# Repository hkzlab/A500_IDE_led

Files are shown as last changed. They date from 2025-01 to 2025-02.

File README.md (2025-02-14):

# A500 IDE activity led injector

## DISCLAIMER

Any use of this project is **under your own responsibility**.
You will be responsible of checking the correct construction and functionality of your board.
By using this project You will agree that I cannot be held responsible if it will destroy any of your devices, damage your computer, burn down your house or whatever.

## Introduction

This board reproduces the same circuit that the A500 uses to flash the "DRIVE" LED when the `/MTR0` signal is toggled, and puts itself in parallel to that 
by being installed between the keyboard and the connector on the motherboard.

It is useful to have the LED blink for other activity beside the floppy's, ideally, IDE hard drive activity.

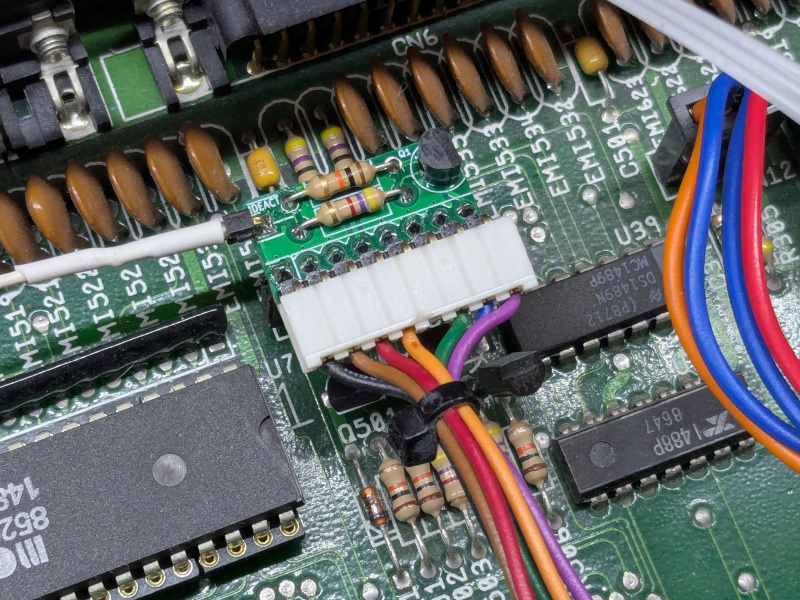
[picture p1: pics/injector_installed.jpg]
Board installed in an A500 rev.3


The IDE activity signal must then be taken from the IDE connector, on a 44 pin connector, it is on pin 39.

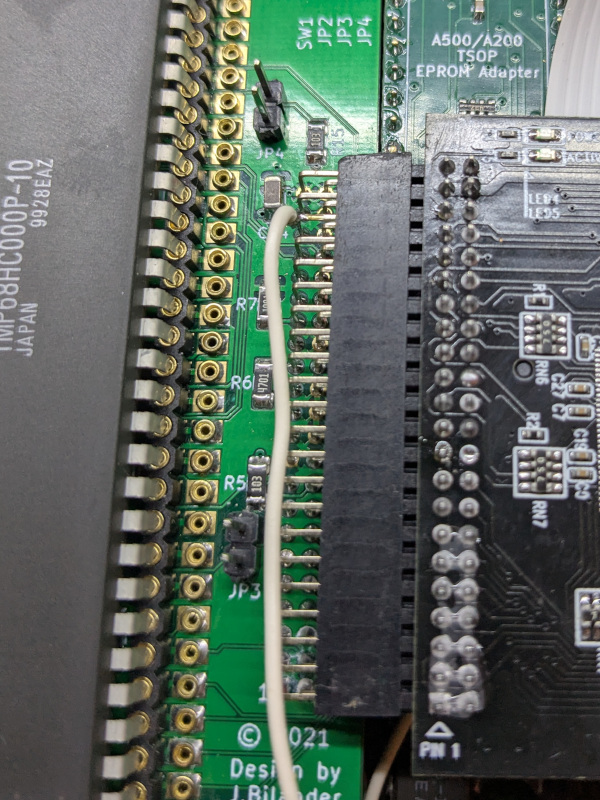
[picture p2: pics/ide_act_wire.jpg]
Wire soldered on connector pin 39


### Ordering the boards

You can order the board for this project at [PCBWay](https://www.pcbway.com/project/shareproject/A500_IDE_LED_mod_board_fed31fc6.html) and support me or download 
the gerbers and have them printed wherever you like!!!

## Hardware

The board was designed with [KiCad](https://kicad.org/) EDA.

### Bill of Materials

| Component | Qty | Type / Value | Notes |
| --- | --- | --- | --- |
| R1 |  1  | 4.7K 1/4W THT resistor | |
| R2 |  1  | 10K 1/4W THT resistor | |
| Q1 |  1  | 2N3906 TO-92 transistor | |
| J1 |  1  | 8pin, 2.54mm pitch socket | Mount on the underside of the board |
| J2 |  1  | 8pin, 2.54mm pitch header | straight pins are fine, use right angled ones for a better fit |
| J3 |  1  | 1pin | Optional, you can solder the activity wire here or use a header |
| U1 |  1  | 74AHCT1G07 SOT-353 | Optional, see note below |
| R3 |  1  | 10K 0805 SMD resistor | Optional, see note below |
| C1 |  1  | 100nF/16V 0805 SMD capacitor | Optional, see note below |

Components U1, R3 and C1 implement a buffer for the /IDE_ACTIVITY signal, which is useful if you notice that the activity LED in the A500 remains faintly lit
when the adapter is installed (happens when the high level for the signal is not high enough to completely shut the transistor off).

If these components are omitted, close the jumper JP1.

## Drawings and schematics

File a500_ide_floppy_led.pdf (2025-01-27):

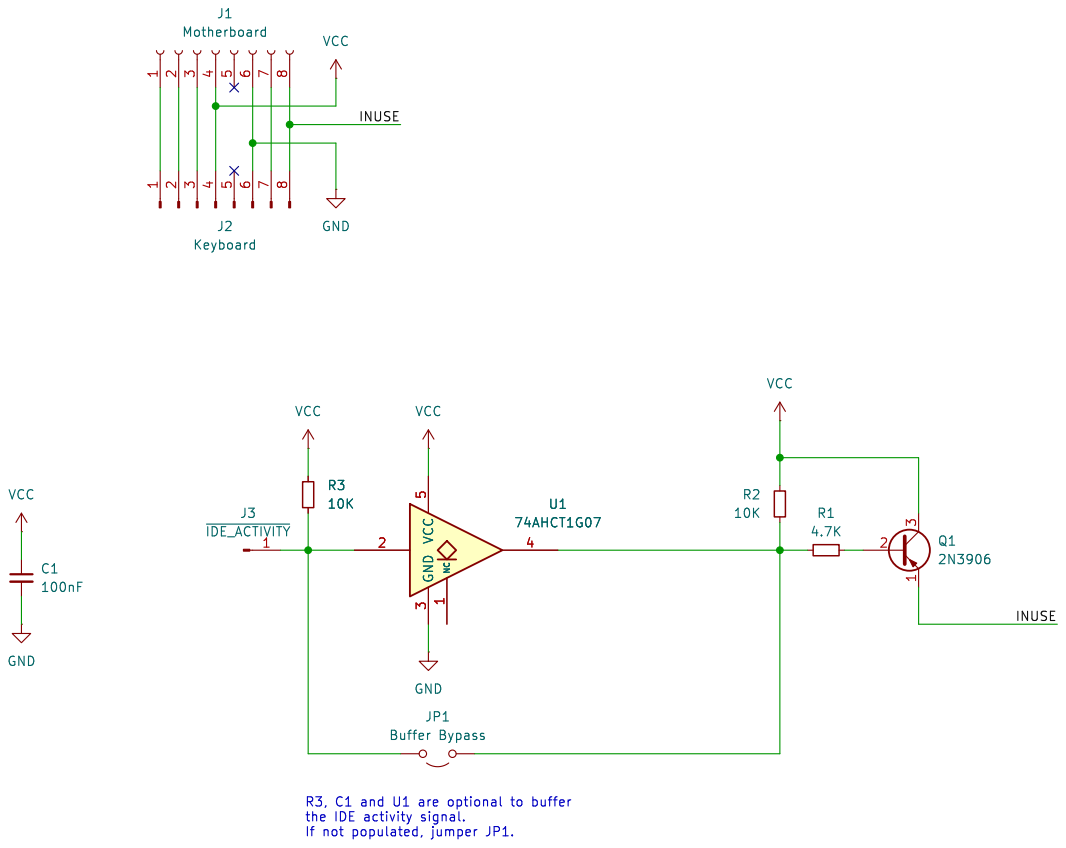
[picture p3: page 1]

Id: 1/1 Title: File: a500_ide_floppy_led.kicad_sch Sheet: /

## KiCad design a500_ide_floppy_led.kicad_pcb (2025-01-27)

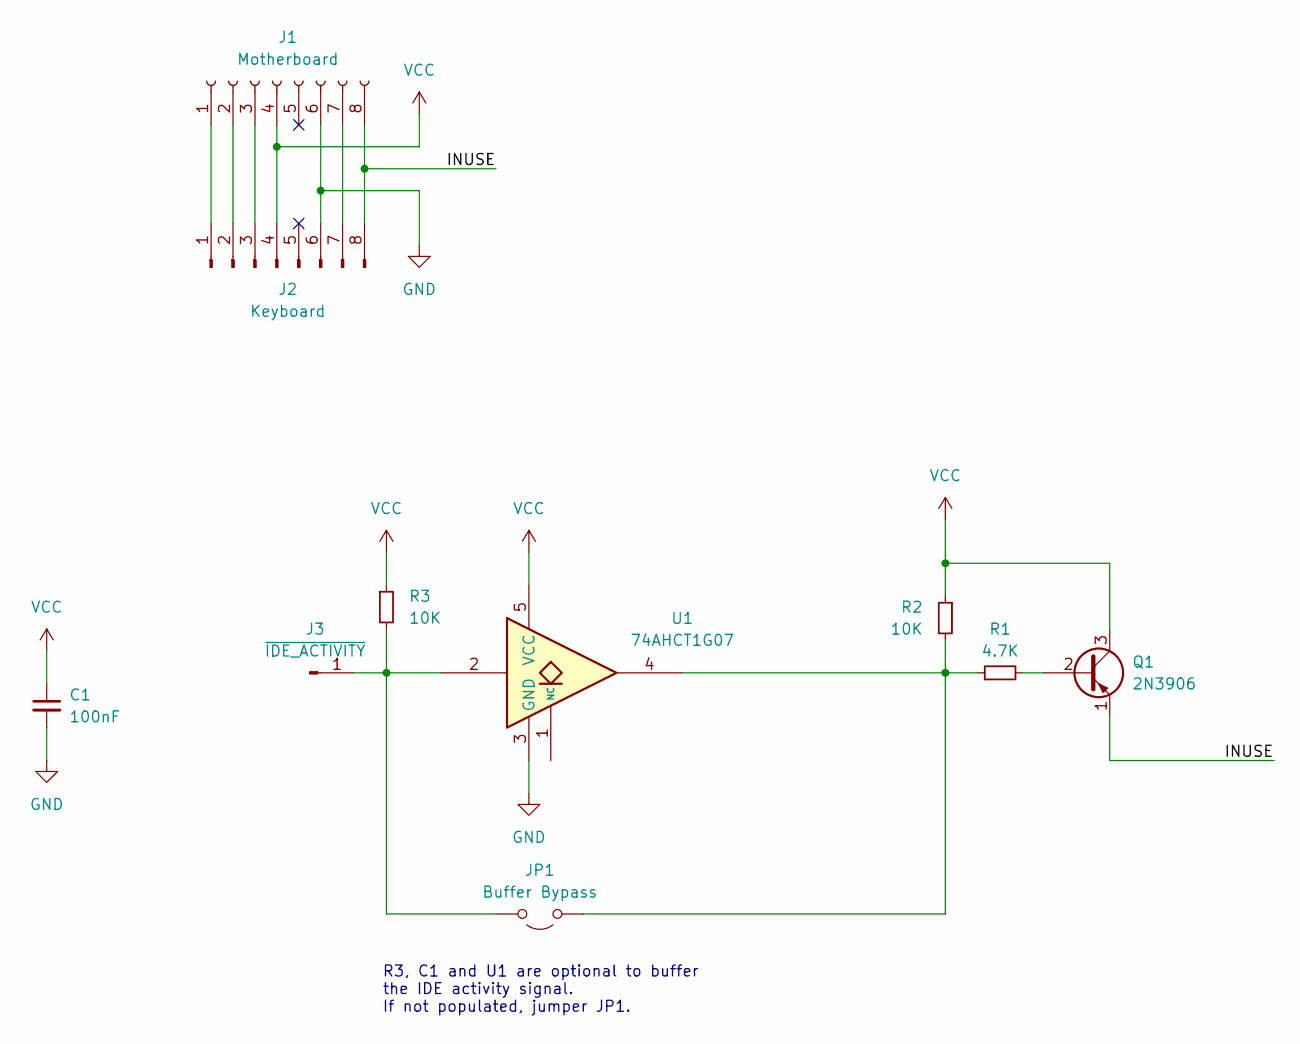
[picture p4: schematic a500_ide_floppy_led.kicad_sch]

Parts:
C1: 100nF; C_0805_2012Metric_Pad1.18x1.45mm_HandSolder
J1: Motherboard; PinSocket_1x08_P2.54mm_Vertical
J2: Keyboard; PinHeader_1x08_P2.54mm_Vertical
J3: ~{IDE_ACTIVITY}; PinHeader_1x01_P2.54mm_Vertical
JP1: Buffer Bypass; SolderJumper-2_P1.3mm_Open_RoundedPad1.0x1.5mm
Q1: 2N3906; TO-92_Inline
R1: 4.7K; R_Axial_DIN0207_L6.3mm_D2.5mm_P10.16mm_Horizontal
R2: 10K; R_Axial_DIN0207_L6.3mm_D2.5mm_P10.16mm_Horizontal
R3: 10K; R_0805_2012Metric_Pad1.20x1.40mm_HandSolder
U1: 74AHCT1G07; SOT-353_SC-70-5_Handsoldering

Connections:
/INUSE: J1.8, J2.8, Q1.1 (E)
GND: C1.2, J1.6, J2.6, U1.3 (GND)
unnamed: J1.1, J2.1
unnamed: J1.2, J2.2
unnamed: J1.3, J2.3
unnamed: J1.7, J2.7
unnamed: J3.1, JP1.2 (B), R3.2, U1.2
unnamed: JP1.1 (A), R1.1, R2.2, U1.4
unnamed: Q1.2 (B), R1.2
VCC: C1.1, J1.4, J2.4, Q1.3 (C), R2.1, R3.1, U1.5 (VCC)

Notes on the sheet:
R3, C1 and U1 are optional to buffer the IDE activity signal. If not populated, jumper JP1.

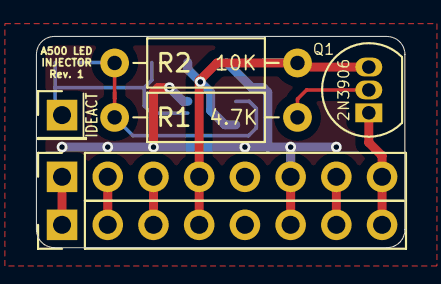
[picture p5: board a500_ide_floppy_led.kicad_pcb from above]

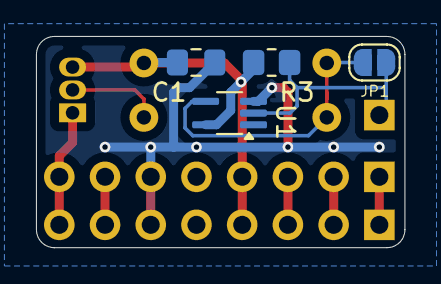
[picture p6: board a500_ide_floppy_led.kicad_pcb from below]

Board: 2 copper layers, 20.5 x 11.7 mm, 10 parts (4 on the bottom side), 10 nets.

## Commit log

2024-12-08 Add ide activity floppy led injector
    [a500_ide_floppy_led.kicad_pcb, a500_ide_floppy_led.kicad_sch]
2024-12-08 Tweak the silkscreen
    [a500_ide_floppy_led.kicad_pcb]
2024-12-08 Slightly shrink the board
    [a500_ide_floppy_led.kicad_pcb]
2024-12-08 Increase trace width for INUSE
    [a500_ide_floppy_led.kicad_pcb]
2024-12-08 Increase track width
    [a500_ide_floppy_led.kicad_pcb]
2025-01-27 Add untested rev.1 that buffers the signal
    [a500_ide_floppy_led.kicad_pcb, a500_ide_floppy_led.kicad_sch]
2025-02-14 Remove rev_0 gerbers
